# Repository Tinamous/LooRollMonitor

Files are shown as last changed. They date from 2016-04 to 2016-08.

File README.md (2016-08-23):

Toilet Roll Monitor
===================

Never run out of toilet paper again!

Internet collected toilet roll pole, constructed of a 3D printed base and a acrylic tube (pole) which the toilet paper rolls are stacked, internet connected with a Particle.io Photon.

The presense of toilet rolls are sensed with a IR reflectance sensor. Reflected IR signal == roll preset, no reflection == no roll.

Uses Photon with WiFi connection which is high power and 20mA drive for 3x IR LEDs, however the Photon can be put in low power mode (no WiFi)
and roll sensing only needs to be done occasionally.

## Why:
* Why not ;-)
* Guest bathrooms you don't check all that often - get notification on low toilet paper before your guess runs out.
* Day to day automation, never forget to order toilet paper again.

### Design issues:

#### V1: 
* Somewhat high power using photon and WiFi, most likely batteries will runout before toilet paper!
* Multiboard design clumsy to solder together but flexible from 1 to 4 roll sensors
* limited connections means all leds are driven at once (@20mA), so 3 roll system sees 60mA spike
* PCB mounted AA battery holders were just a bit too big to fit in the acrylic tube so batteries embedded in the 3D printed base.
* Humidity/temperature sensor, maybe not so useful? Difficult to solder on.

### V2 Options:
* Replace Photon with Bluz (or Zigbee + SmartThings combo).
* Single board to allow better signal routing and less soldering of connections.
* Possible to use PCB mounted coin cells if Bluz low power enough 
* Use through hole version of sensor for easier soldering

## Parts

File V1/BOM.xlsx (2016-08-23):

R1 | 100R | 1206
R2
R3 | 4k7 | 1206
R4 | 4k7 | 1206
R5 | 100k | 1206
R6 | 100k | 1206
R7 | 1k | 1206
C1 | 0.1uF | 805
U1 | HTU21D
D1 | LED | 1206 Reverse

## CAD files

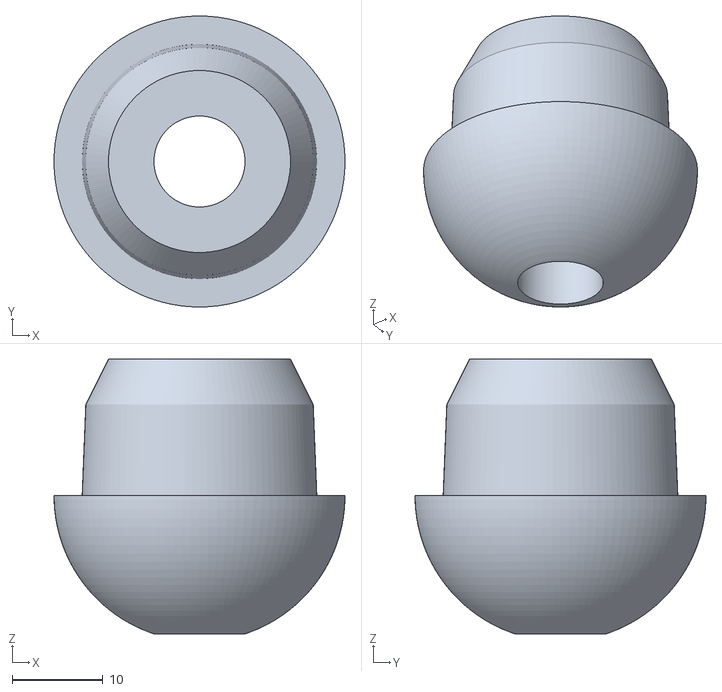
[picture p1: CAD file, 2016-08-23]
3DPrinted/Top.stl
32.0 x 32.0 x 30.2

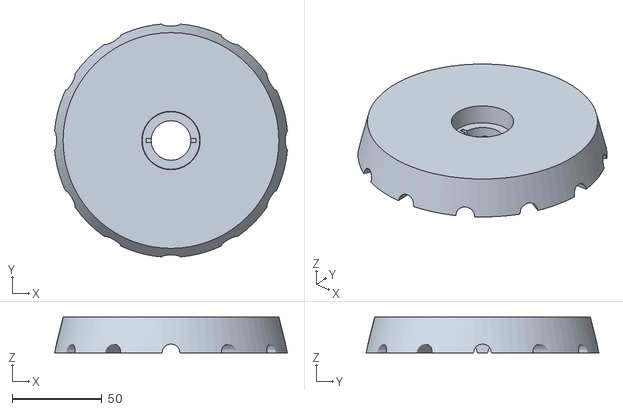
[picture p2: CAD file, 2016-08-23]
3DPrinted/Base-2.stl
129.6 x 129.6 x 20.0

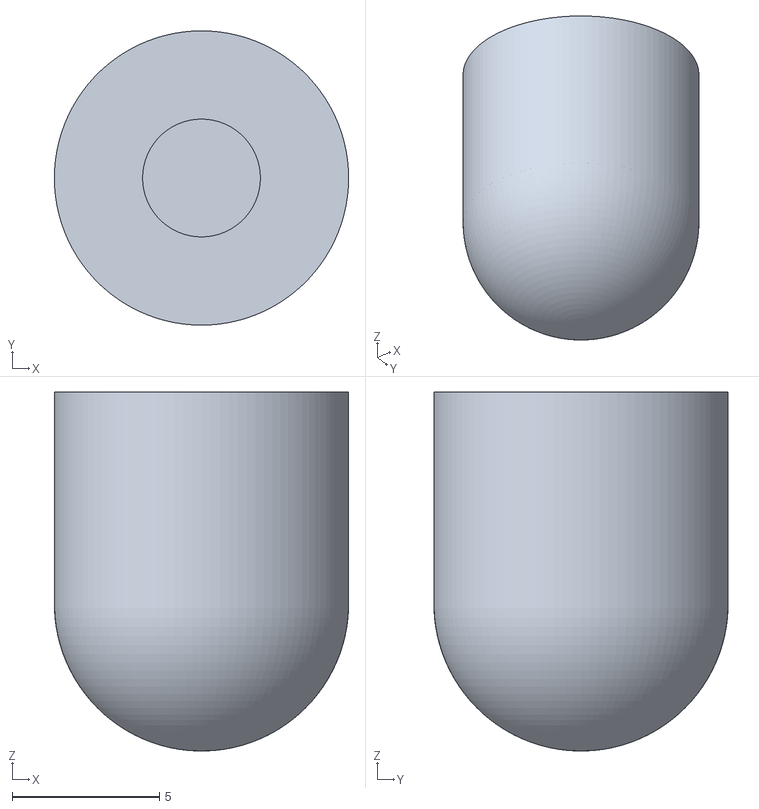
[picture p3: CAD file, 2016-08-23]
3DPrinted/RearPadding.stl
10.0 x 10.0 x 12.2

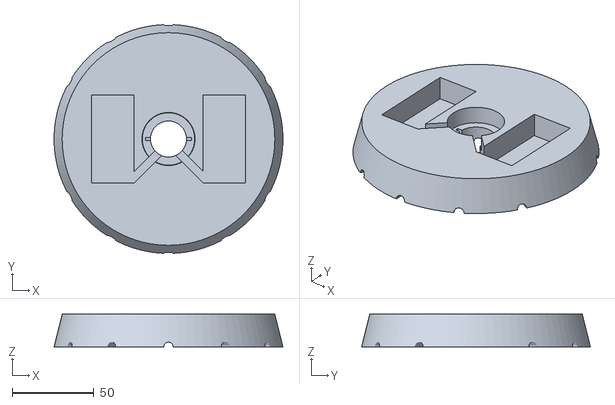
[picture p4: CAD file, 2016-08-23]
3DPrinted/Base-AAA.stl
140.0 x 139.8 x 20.0

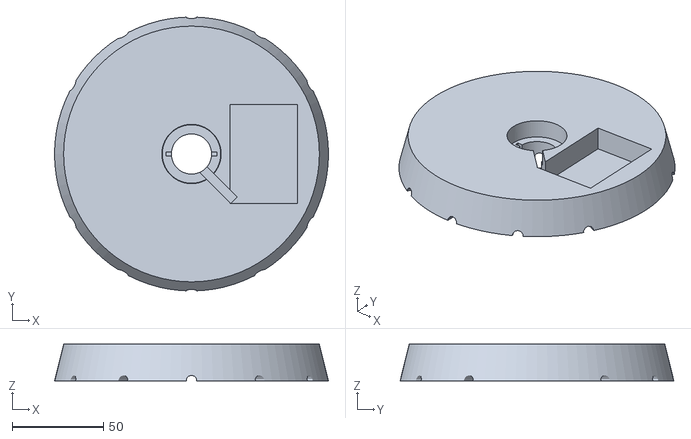
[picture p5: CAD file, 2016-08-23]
3DPrinted/Base.stl
150.0 x 149.8 x 20.0

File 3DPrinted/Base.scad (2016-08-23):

// The height of the base.
baseHeight = 20;
baseRadius = 65; 

// Size of the clear acrylic tube
tubeSize = 32; 
// How far down into the base the tube is expected to go
tubeDepthInBase = baseHeight - 10;

// LiPol cell
//batteryBoxWidth = 37; 
//batteryBoxLength = 54;
//batteryBoxDepth = 13;

// AAA battery.
batteryBoxWidth = 26;
batteryBoxLength = 54;
batteryBoxDepth = 14;



// series of releafes in the base to allow water to run through
// for the water detection part
module waterHoles() {
    for (angle = [30 : 30 : 150]) {
        rotate(a=[angle,90,0]) {
            cylinder(d=6, h=baseRadius+10);
        }
    }
    
    for (angle = [210 : 30 : 330]) {
        rotate(a=[angle,90,0]) {
            cylinder(d=6, h=baseRadius+10);
        }
    }  
}

module batteryCompartment(isTop) {
    translate([(tubeSize/2)+5,-(batteryBoxLength/2), (baseHeight-batteryBoxDepth)]) {
        cube([batteryBoxWidth,batteryBoxLength,batteryBoxDepth]);
        translate([-23,0,0]) {
            //cube([24,5,batteryBoxDepth]);
            translate([0,0,-1]) {
                //cube([5,16,batteryBoxDepth+1]);
            }
        }
        
        if (isTop) {
            translate([4,3.5,0]) {
                rotate(a=135) {
                    cube([28,5,batteryBoxDepth]);
                }
            }
        } else {
            
            translate([0,batteryBoxLength,0]) {
                rotate(a=225) {
                    cube([28,5,batteryBoxDepth]);
                }
            }
        }
    }
}

module base() {
    difference() {
        union() {
            cylinder(r1=baseRadius+5, r2=baseRadius, h=baseHeight, $fn=80);
        }
        union() {
            waterHoles();
            
            batteryCompartment(true);
            
            rotate(a=180) {
                batteryCompartment(false);
            }
            
            // Small inner hole all the way through
            // diameter to match the PCB narrow width used for the 
            // water sensor.
            cylinder(d=22, h=baseHeight, $fn=80);
            
            // 2 vertical pockets for the PCB to rest into.
            translate([10,-1,2]) {
                #cube([4,2,baseHeight]);
            }
            translate([-14,-1,2]) {
                #cube([4,2,baseHeight]);
            }
            
            // tube stops before the bottom of the base
            // Move up so the tube comes through the top of the base
            translate([0,0,baseHeight - tubeDepthInBase]) {
                // Slight angle to give it an easy in and snug fit.
                cylinder(d1=tubeSize, d2 = tubeSize+0.5, h=tubeDepthInBase, $fn=80);
            }
        }
    }
}


base();
//waterHoles();

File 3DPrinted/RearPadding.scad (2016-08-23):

// Tube ID 26mm
// PCB width = 1.6mm
// == 24.4mm to cover.
// /2 = 12.2mm padding either side of the PCB.
//
// 

$fn=100;
difference() {
    union() {
        // 14mm between PCB and tube.
        sphere(5); // 5mm rad. 
        cylinder(d=10,h=7.2); // 12.2 - 5 == 7.2
    }

    union() {
        translate([0,0,2]) {
            #cylinder(d=4,h=12.2);
        }
    }
}

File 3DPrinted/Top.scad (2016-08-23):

// Tube ID: 26mm
// Tube OD: 32mm 
// PCB width = 1.6mm


$fn=100;

module topBall() {
    difference() {
        union() {
            sphere(16);
            cylinder(d=10,h=7.2);
        }
        union() {
            translate([-16,-16,0]) {
                cube([32, 32, 32], centre=true);
            }
        }
    }
}


difference() {
    union() {
        topBall();
        // sloped cylinder to help fit
        cylinder(d1=25.8, d2=25, h=10);
        translate([0,0,10]) {
            cylinder(d1=25, d2=20, h=5);
        }
    }
    union() {
        translate([0,0,-20]) {
            #cylinder(d=10, h=40);
        }
    }
}

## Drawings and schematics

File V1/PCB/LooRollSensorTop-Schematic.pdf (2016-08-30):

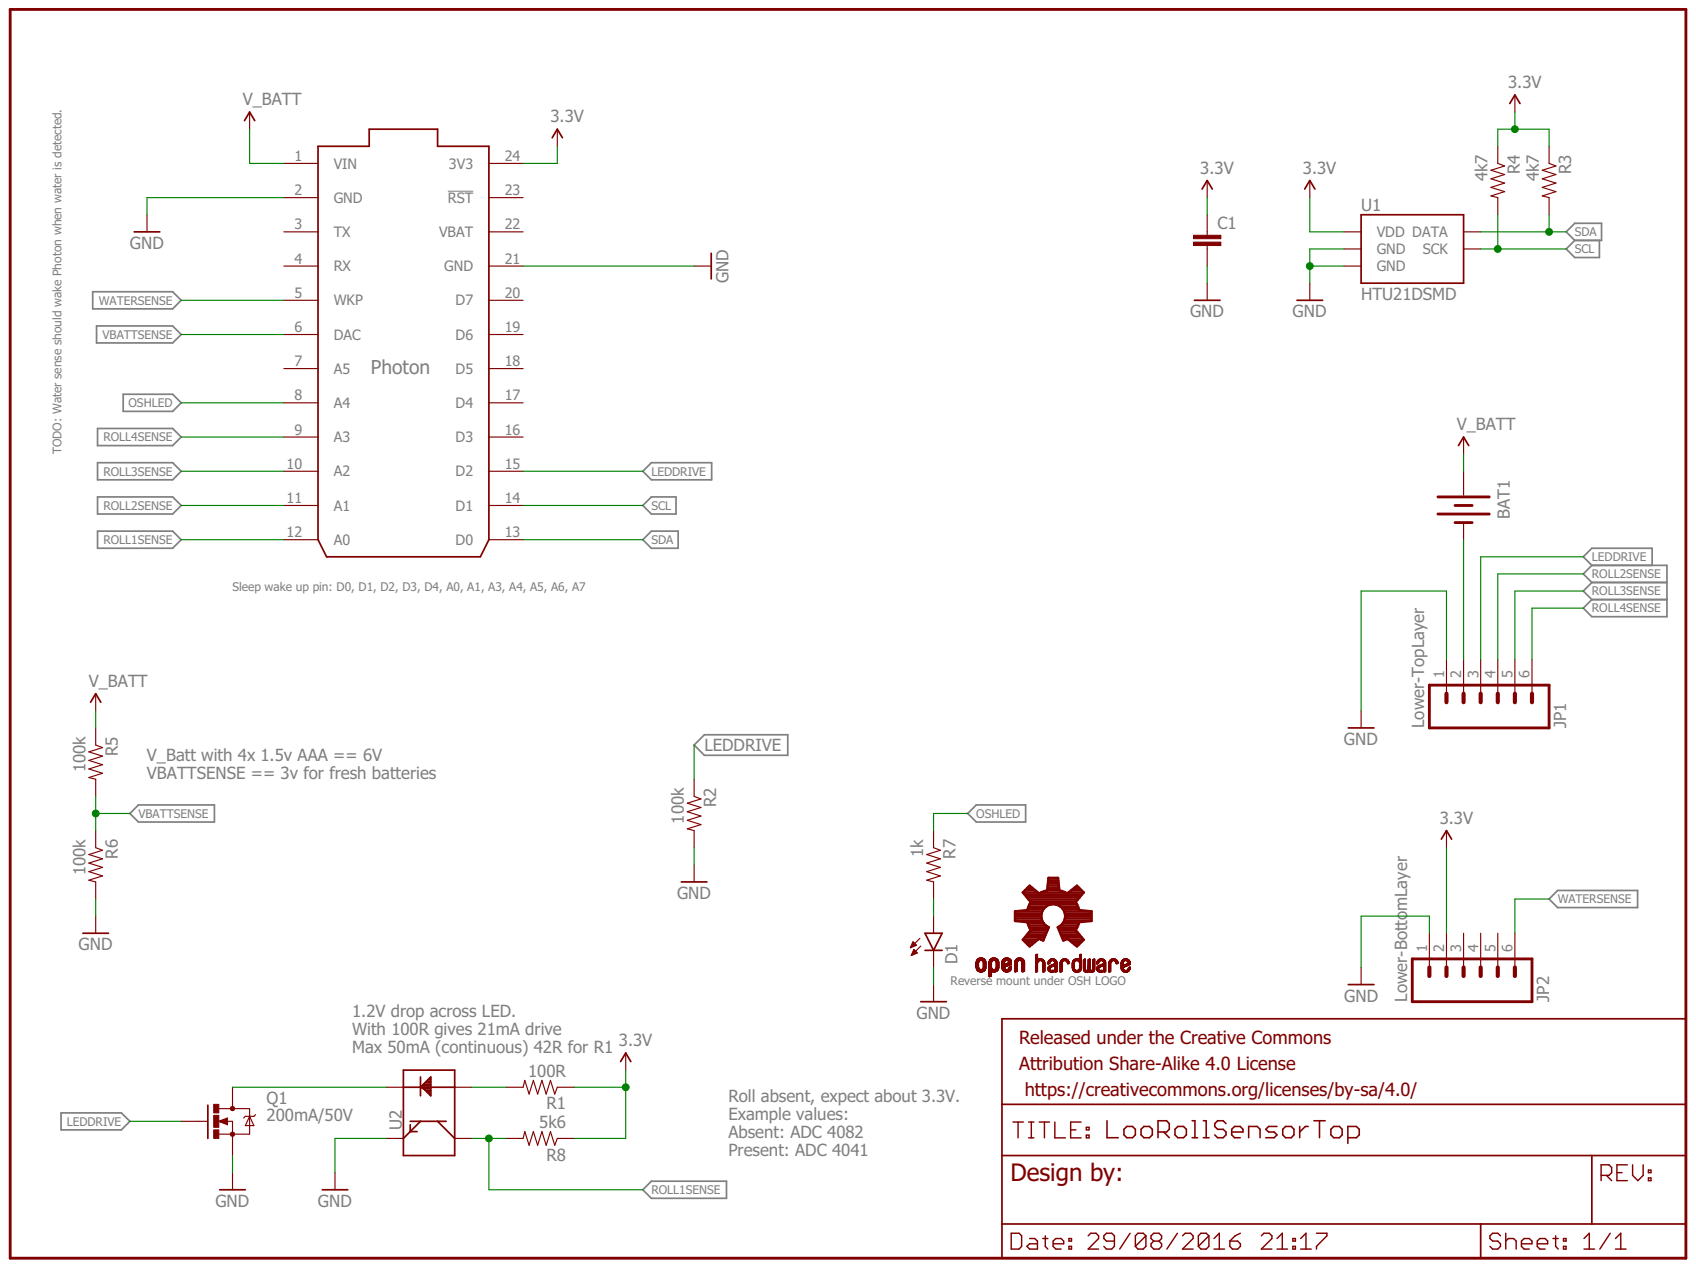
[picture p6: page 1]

TODO: Water sense should wake Photon when water is detected.

Sleep wake up pin: D0, D1, D2, D3, D4, A0, A1, A3, A4, A5, A6, A7

V_Batt with 4x 1.5v AAA == 6V
VBATTSENSE == 3v for fresh batteries

Reverse mount under OSH LOGO 1.2V drop across LED. With 100R gives 21mA drive Max 50mA (continuous) 42R for R1

Released under the Creative Commons Attribution Share-Alike 4.0 License https://creativecommons.org/licenses/by-sa/4.0/

Roll absent, expect about 3.3V. Example values: Absent: ADC 4082

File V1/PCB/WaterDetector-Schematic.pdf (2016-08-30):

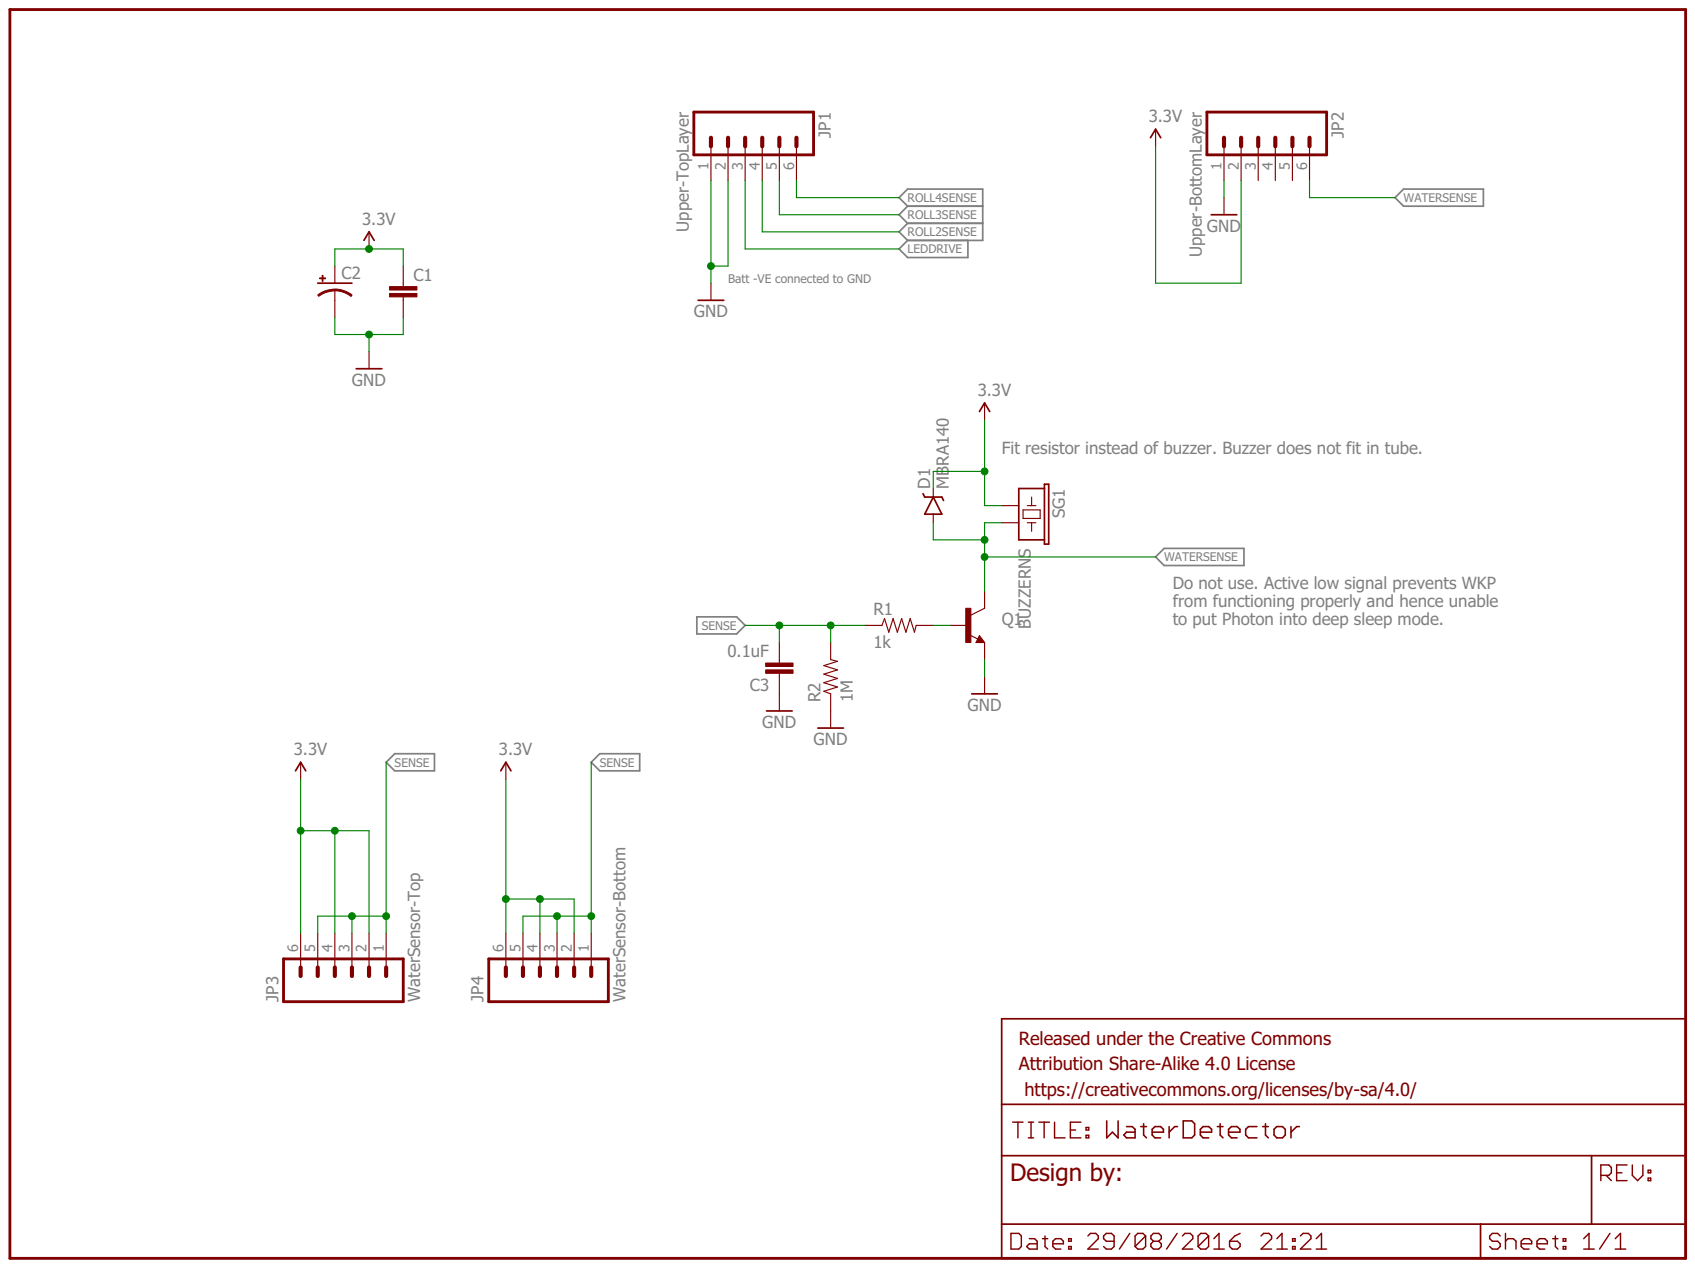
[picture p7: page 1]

Batt -VE connected to GND

Fit resistor instead of buzzer. Buzzer does not fit in tube.

Do not use. Active low signal prevents WKP
from functioning properly and hence unable
to put Photon into deep sleep mode.

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

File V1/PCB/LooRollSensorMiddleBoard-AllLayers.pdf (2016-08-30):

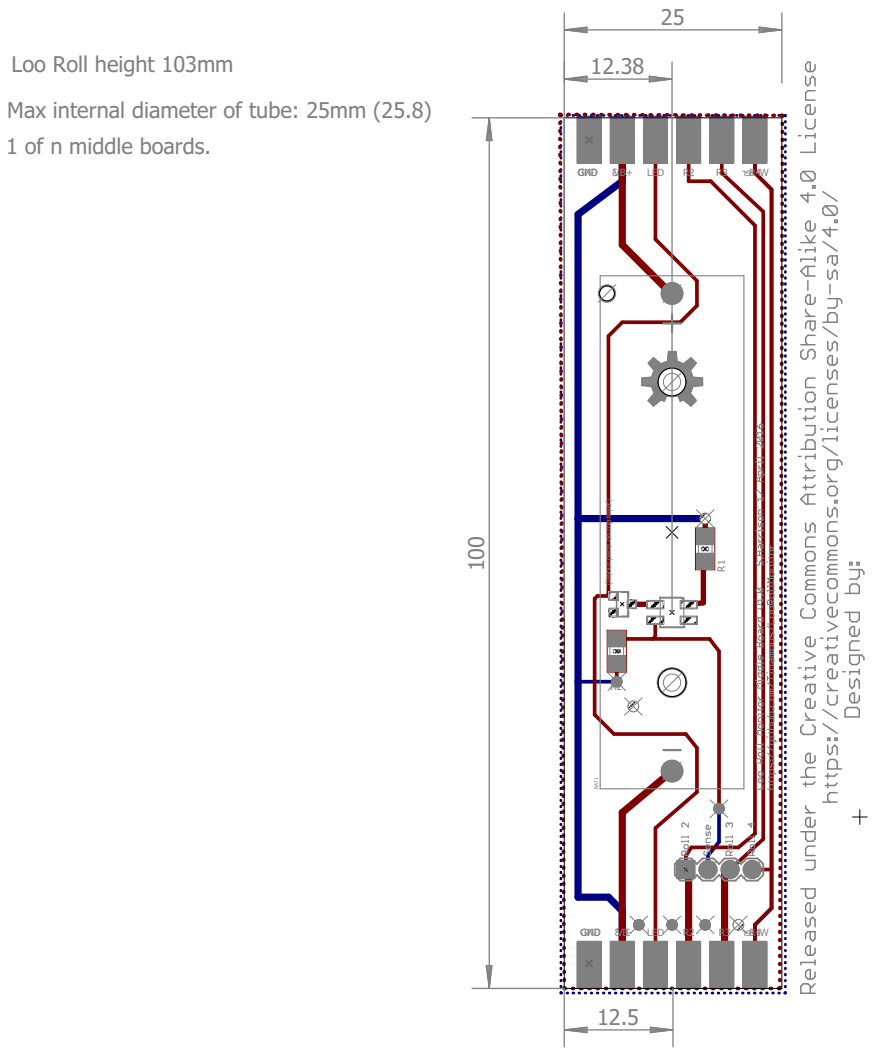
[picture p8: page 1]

Max internal diameter of tube: 25mm (25.8)

(layout parts on top layer)

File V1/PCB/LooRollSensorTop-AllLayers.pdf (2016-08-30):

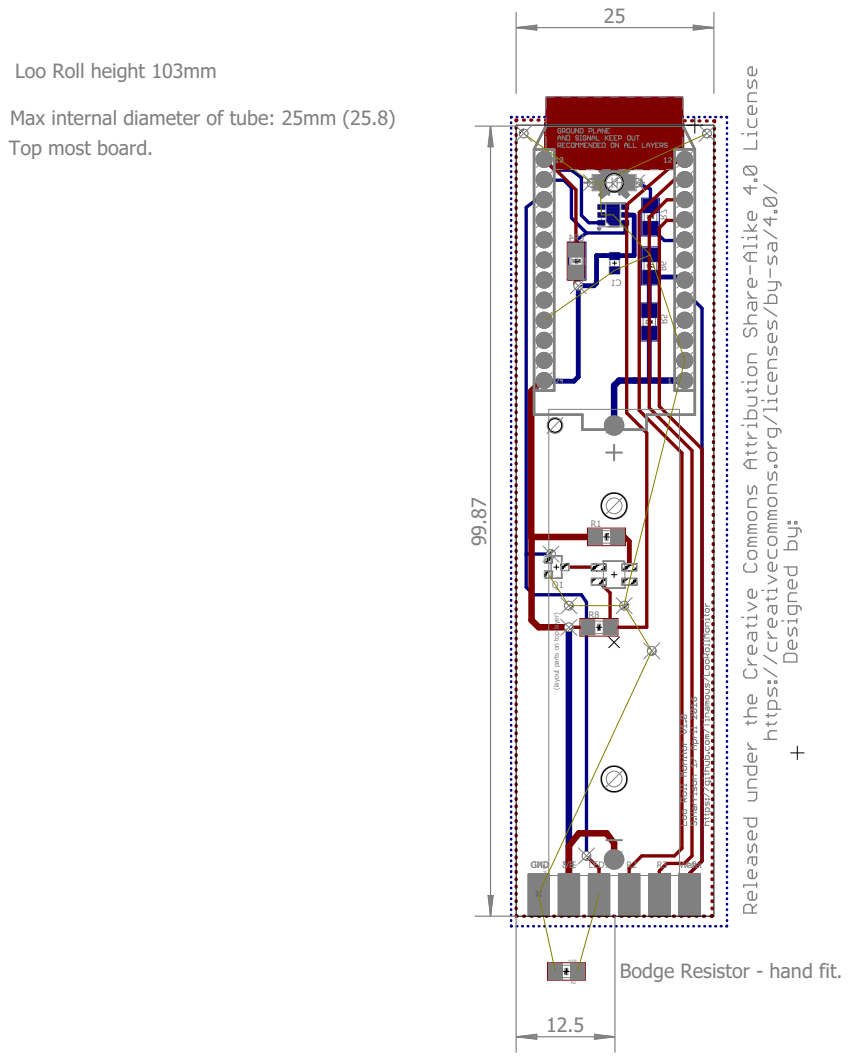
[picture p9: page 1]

Max internal diameter of tube: 25mm (25.8)

(layout parts on top layer)

Bodge Resistor - hand fit.

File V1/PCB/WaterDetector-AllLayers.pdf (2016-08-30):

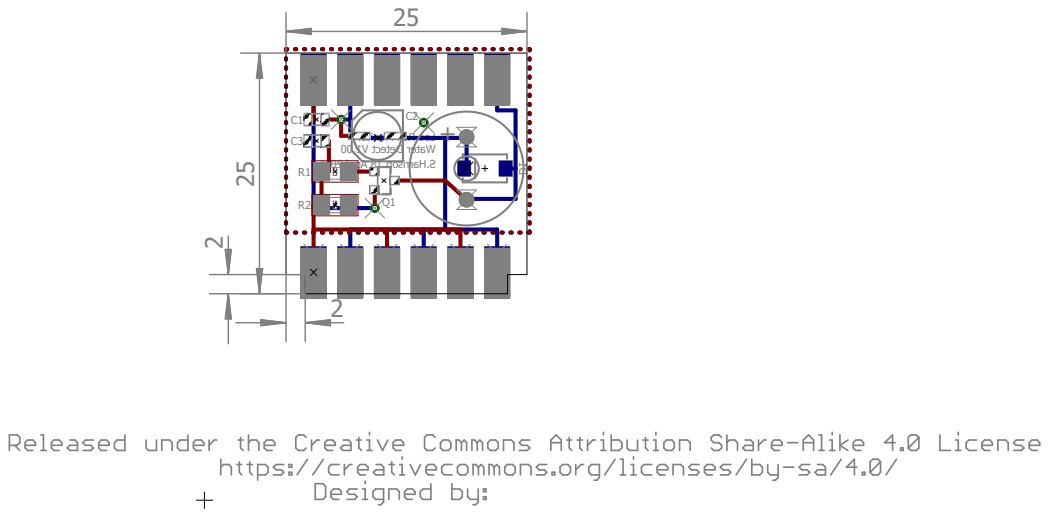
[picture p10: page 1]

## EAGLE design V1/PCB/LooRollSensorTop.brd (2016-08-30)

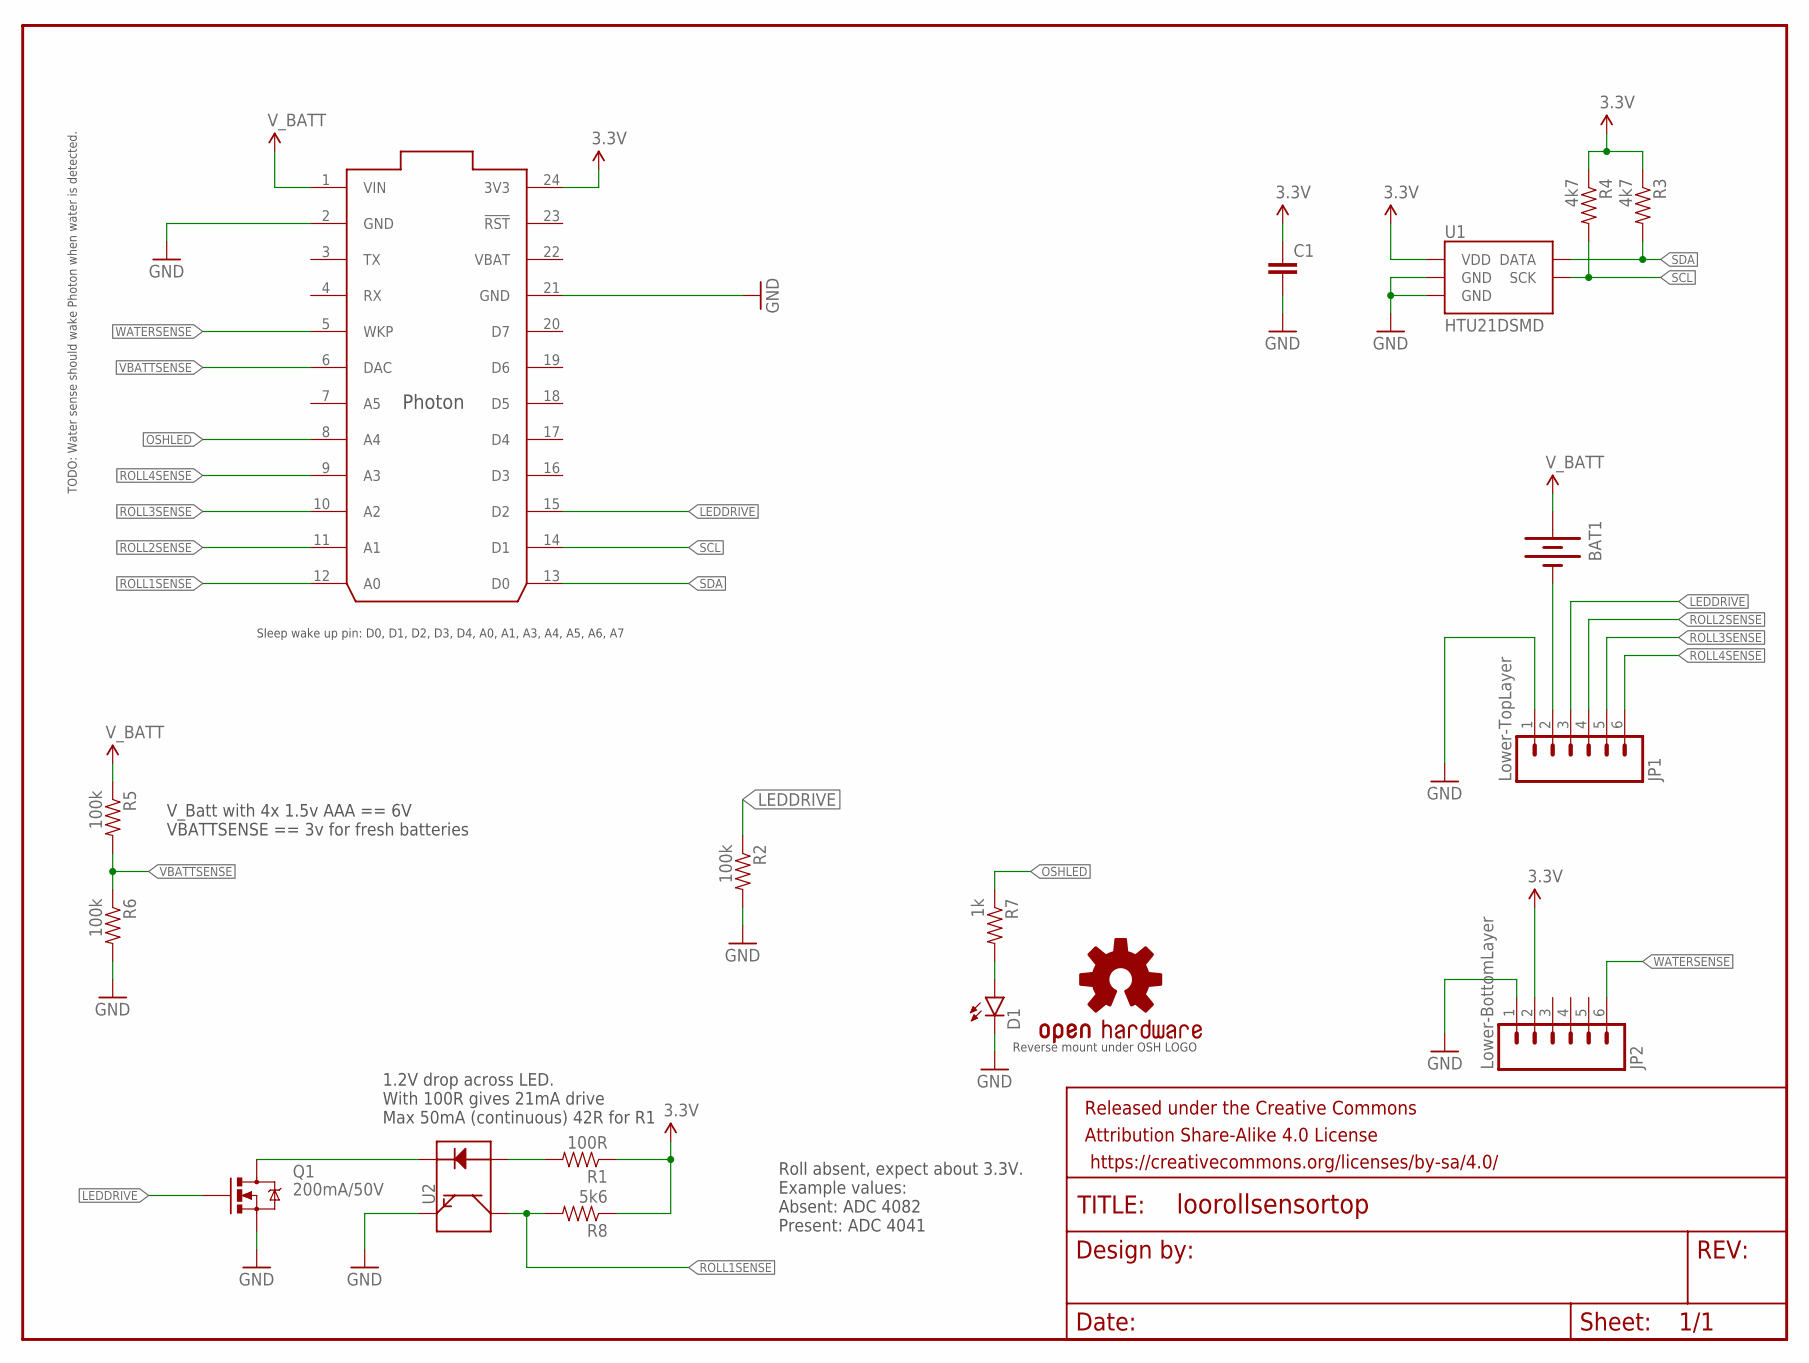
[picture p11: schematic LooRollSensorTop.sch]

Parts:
BAT1: BATTERYAA-PANEL; BATTERY-AA-PANEL; FARNELL 1650669
C1: CAP0805; 0805
D1: LED1206-BOTTOM; LED-1206-BOTTOM
FRAME1: FRAME-LETTER; CREATIVE_COMMONS
JP1: Lower-TopLayer; 1X06-SMD_EDGE
JP2: Lower-BottomLayer; 1X06-SMD_EDGE
LOGO1: OSHW-LOGOM; OSHW-LOGO-M
Q1: 200mA/50V; SOT23-3
R1: 100R; 1206
R2, R5, R6: 100k; 1206
R3, R4: 4k7; 1206
R7: 1k; 1206
R8: 5k6; 1206
U1: HTU21DSMD; HTU21D
U2: QRE1113SMD-W; QRE1113-W
U$1: PHOTON_WITH_HEADERS; PHOTON

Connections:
3.3V: C1.1, JP2.2, R1.1, R3.1, R4.1, R8.1, U1.VDD, U$1.24 (3V3)
GND: C1.2, D1.C, JP1.1, JP2.1, Q1.2 (S), R2.2, R6.2, U1.7 (GND), U1.GND, U2.4 (E), U$1.2 (GND), U$1.21 (GND)
LEDDRIVE: JP1.3, Q1.1 (G), R2.1, U$1.15 (D2)
unnamed: Q1.3 (D), U2.2 (K)
unnamed: R1.2, U2.1 (A)
unnamed: D1.A, R7.2
unnamed: BAT1.-, JP1.2
OSHLED: R7.1, U$1.8 (A4)
ROLL1SENSE: R8.2, U2.3 (C), U$1.12 (A0)
ROLL2SENSE: JP1.4, U$1.11 (A1)
ROLL3SENSE: JP1.5, U$1.10 (A2)
ROLL4SENSE: JP1.6, U$1.9 (A3)
SCL: R4.2, U1.SCK, U$1.14 (D1)
SDA: R3.2, U1.DATA, U$1.13 (D0)
VBAT: U$1.22 (VBAT)
VBATTSENSE: R5.2, R6.1, U$1.6 (DAC)
V_BATT: BAT1.+, R5.1, U$1.1 (VIN)
WATERSENSE: JP2.6, U$1.5 (WKP)

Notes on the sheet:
Sleep wake up pin: D0, D1, D2, D3, D4, A0, A1, A3, A4, A5, A6, A7
TODO: Water sense should wake Photon when water is detected.
Reverse mount under OSH LOGO
1.2V drop across LED. With 100R gives 21mA drive Max 50mA (continuous) 42R for R1
Roll absent, expect about 3.3V. Example values: Absent: ADC 4082 Present: ADC 4041
V_Batt with 4x 1.5v AAA == 6V VBATTSENSE == 3v for fresh batteries

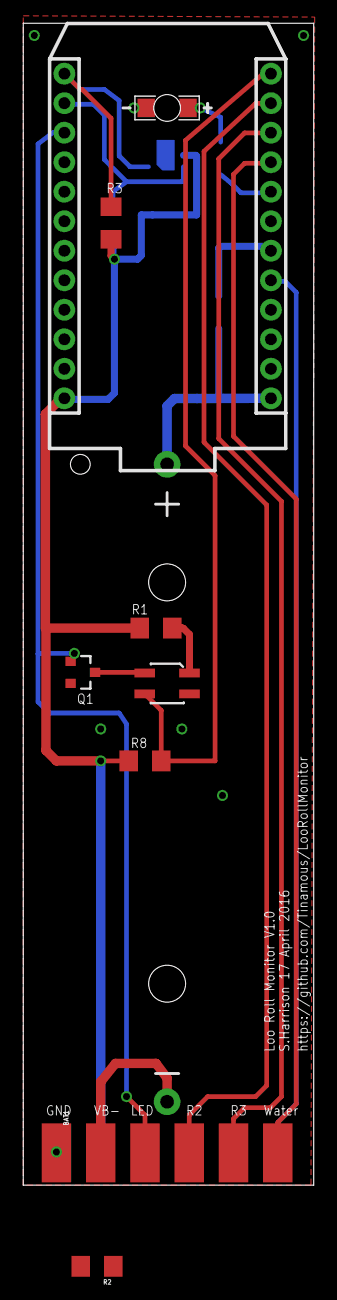
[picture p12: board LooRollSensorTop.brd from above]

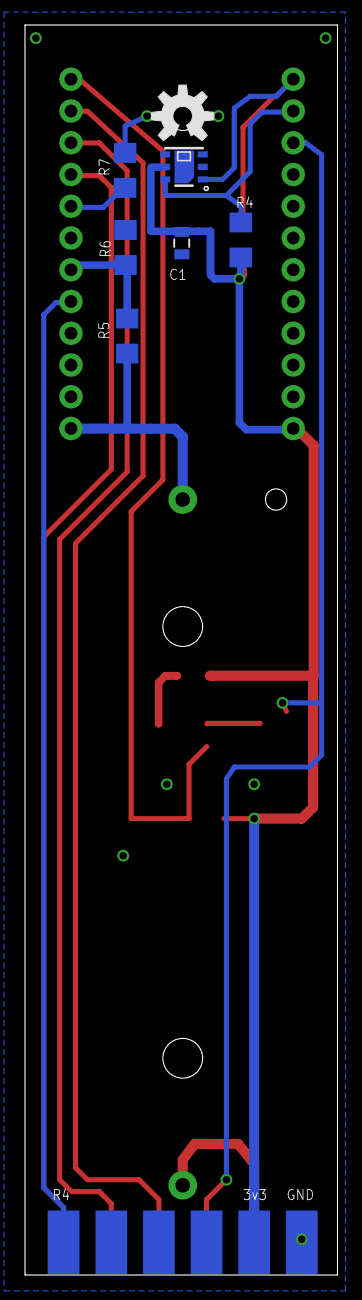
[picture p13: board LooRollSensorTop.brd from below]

Board: 2 copper layers, 25.0 x 100.0 mm, 19 parts (8 on the bottom side), 17 nets.

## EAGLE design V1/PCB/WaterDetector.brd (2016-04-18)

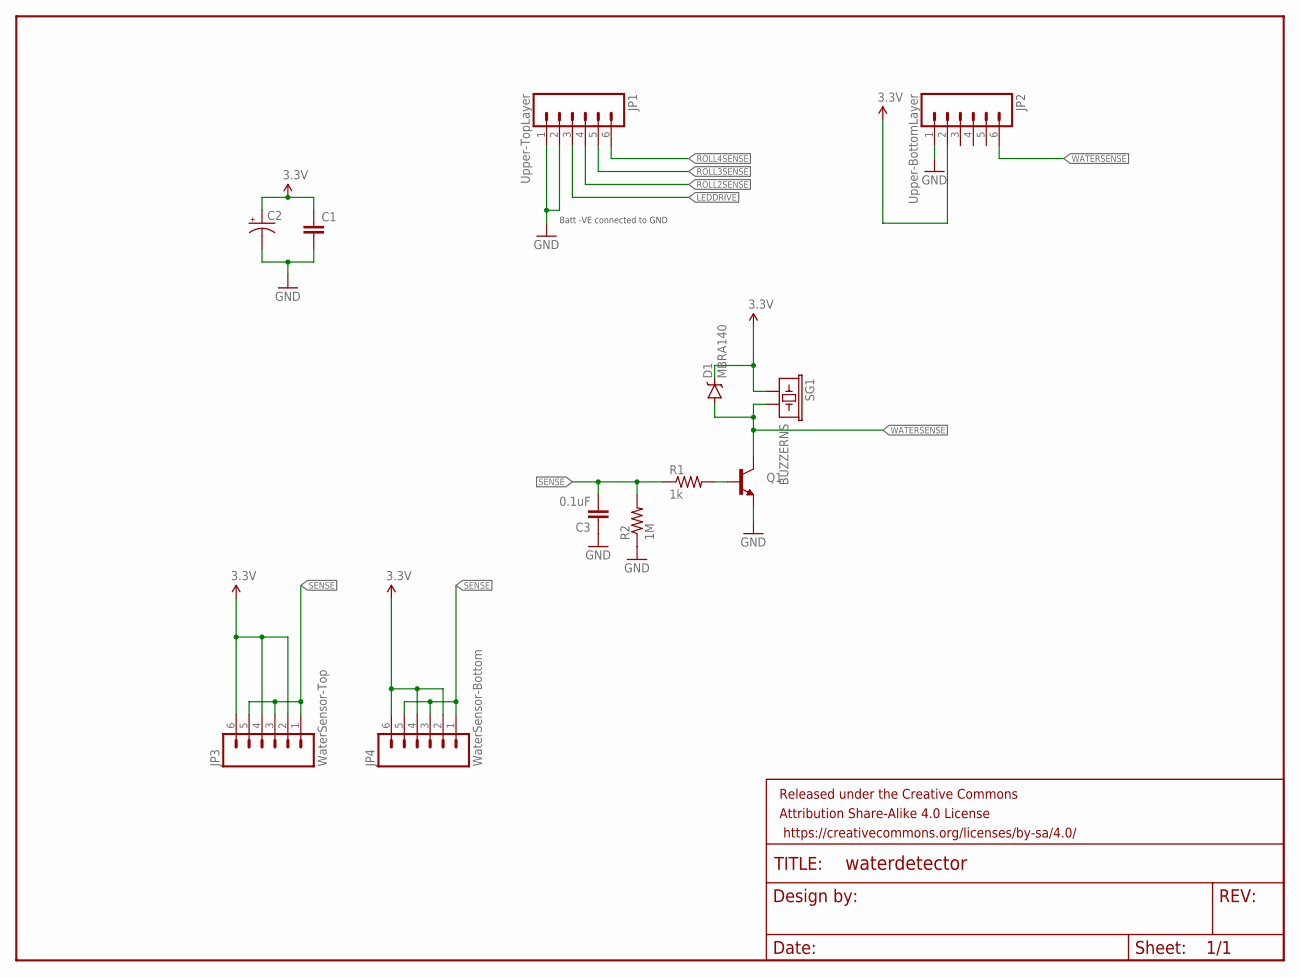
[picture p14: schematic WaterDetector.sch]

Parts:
C1: CAP0805; 0805
C2: CAP_POLC; PANASONIC_C
C3: 0.1uF; 0805
D1: MBRA140; SMA-DIODE
FRAME1: FRAME-LETTER; CREATIVE_COMMONS
JP1: Upper-TopLayer; 1X06-SMD_EDGE
JP2: Upper-BottomLayer; 1X06-SMD_EDGE
JP3: WaterSensor-Top; 1X06-SMD_EDGE
JP4: WaterSensor-Bottom; 1X06-SMD_EDGE
Q1: TRANSISTOR_NPNSOT23-3; SOT23-3
R1: 1k; 1206
R2: 1M; 1206
SG1: BUZZERNS; BUZZER-12MM-NS

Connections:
3.3V: C1.1, C2.+, D1.C, JP2.2, JP3.2, JP3.4, JP3.6, JP4.2, JP4.4, JP4.6, SG1.+ (1)
GND: C1.2, C2.-, C3.1, JP1.1, JP1.2, JP2.1, Q1.2 (E), R2.1
LEDDRIVE: JP1.3
unnamed: Q1.1 (B), R1.2
ROLL2SENSE: JP1.4
ROLL3SENSE: JP1.5
ROLL4SENSE: JP1.6
SENSE: C3.2, JP3.1, JP3.3, JP3.5, JP4.1, JP4.3, JP4.5, R1.1, R2.2
WATERSENSE: D1.A, JP2.6, Q1.3 (C), SG1.- (2)

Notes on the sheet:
Batt -VE connected to GND

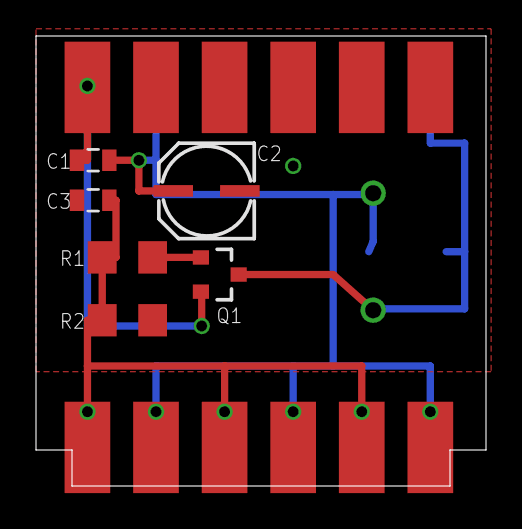
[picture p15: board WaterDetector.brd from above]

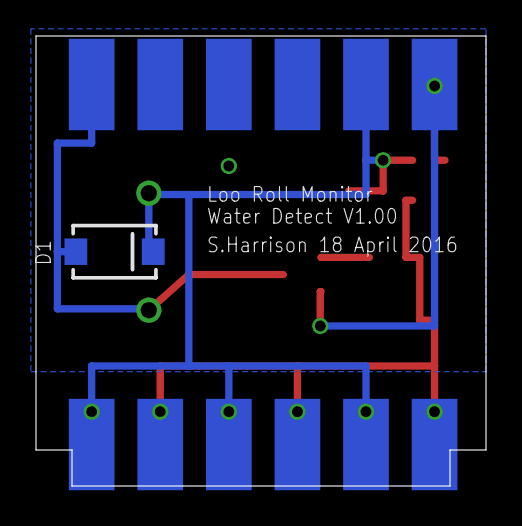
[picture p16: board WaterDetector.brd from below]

Board: 2 copper layers, 25.0 x 25.0 mm, 13 parts (3 on the bottom side), 5 nets.

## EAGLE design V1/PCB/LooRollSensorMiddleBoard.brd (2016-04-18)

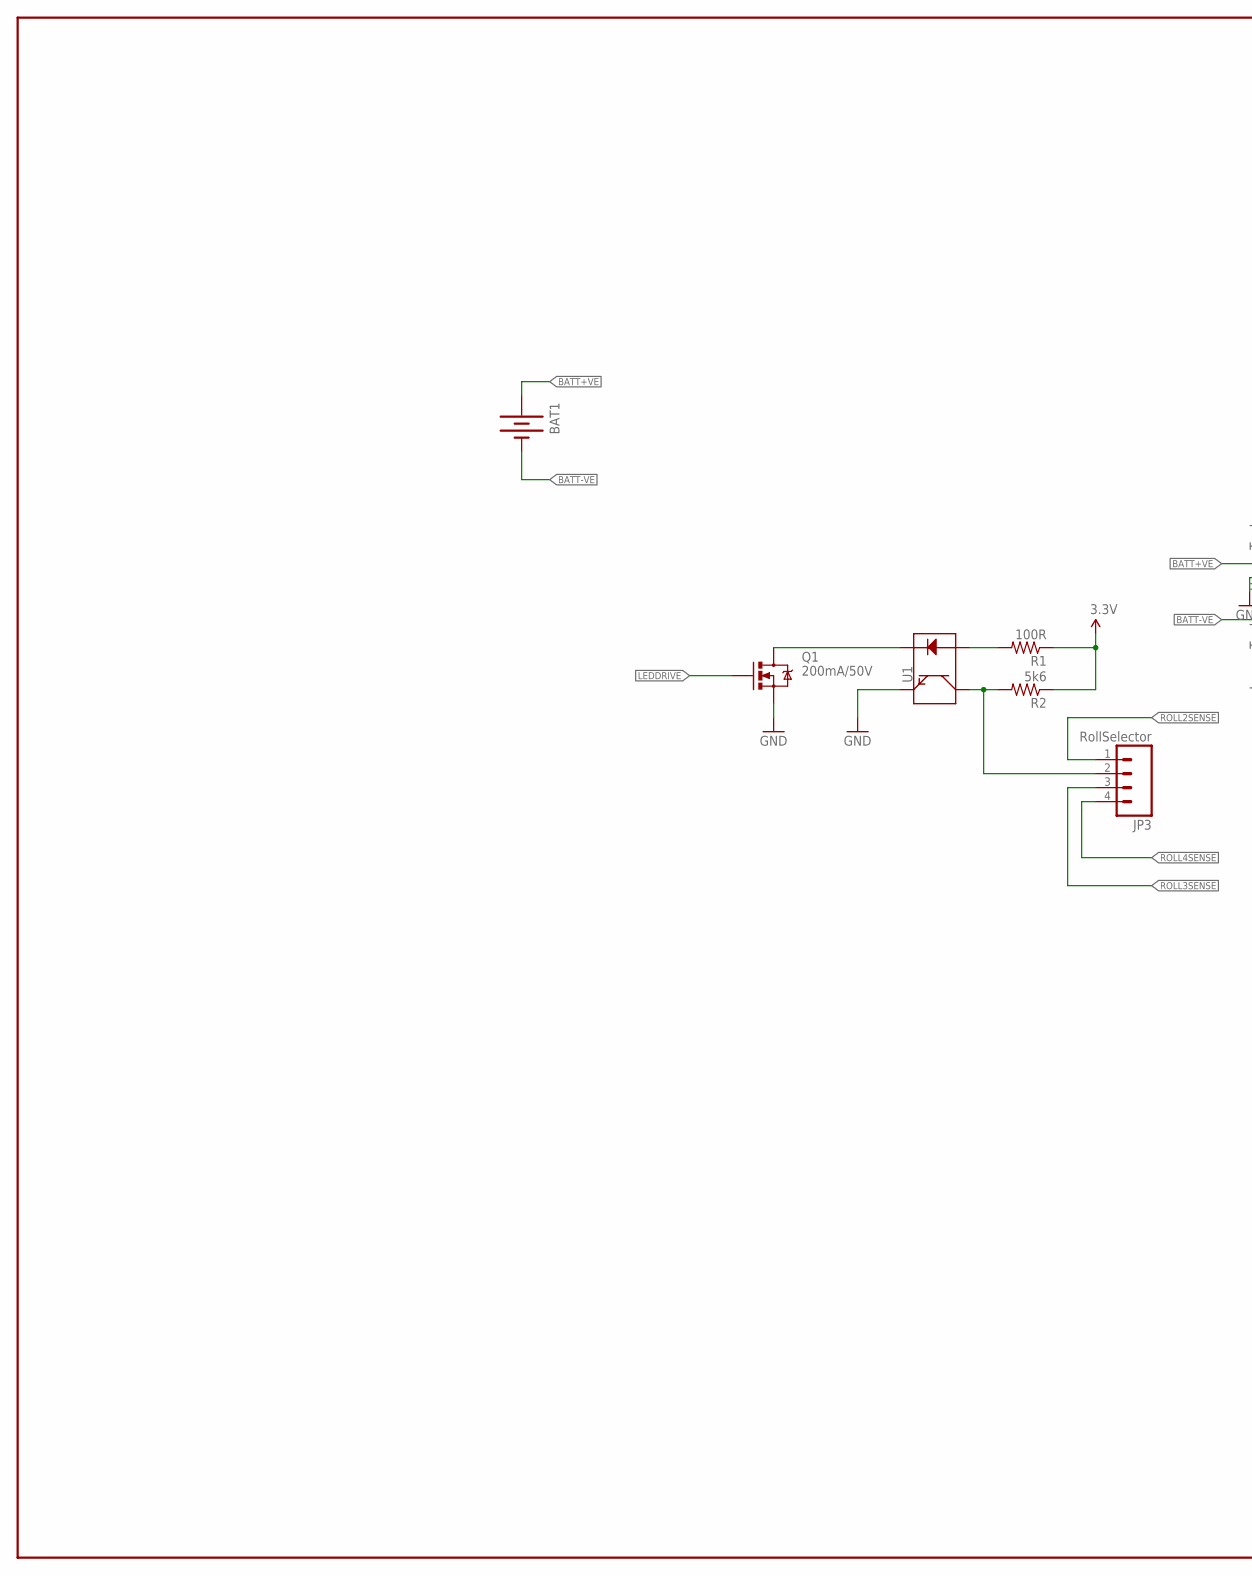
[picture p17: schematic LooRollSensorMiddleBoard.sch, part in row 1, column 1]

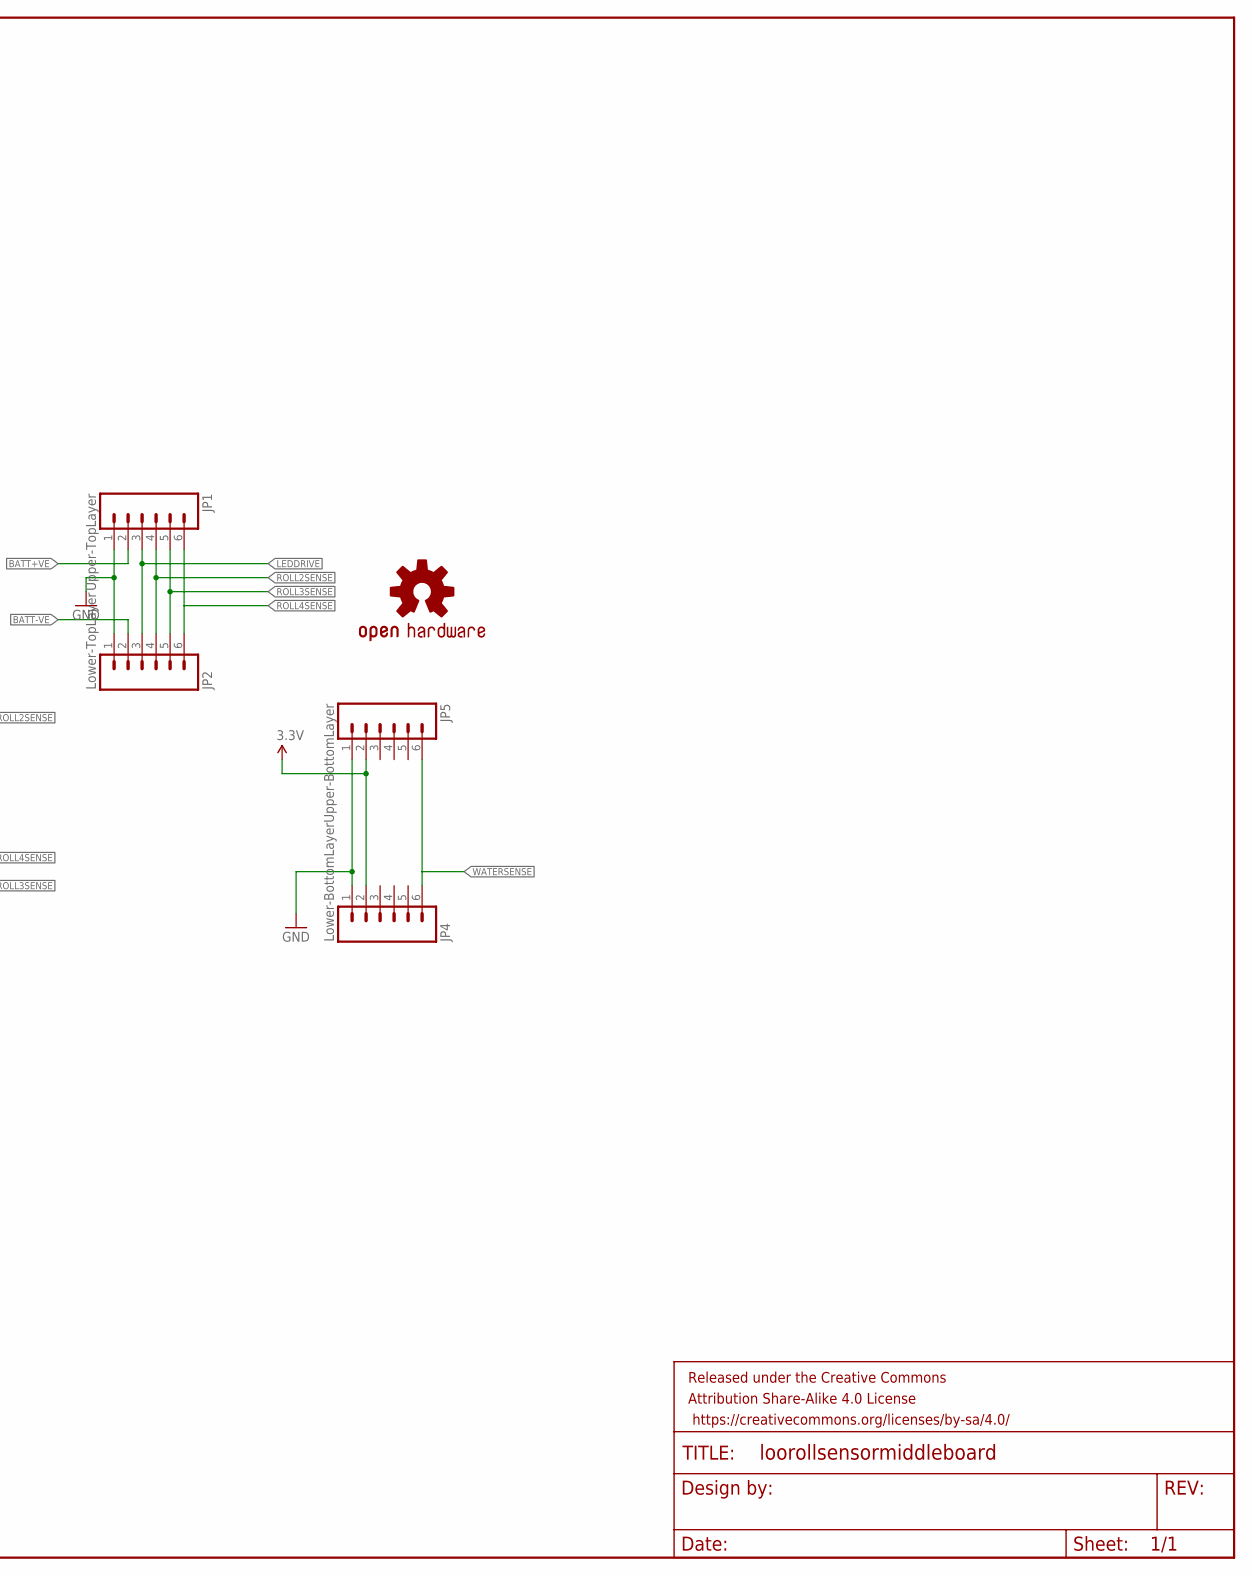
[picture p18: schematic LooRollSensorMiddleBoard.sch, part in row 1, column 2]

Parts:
BAT1: BATTERYAA-PANEL; BATTERY-AA-PANEL
FRAME1: FRAME-LEDGER; CREATIVE_COMMONS
JP1: Upper-TopLayer; 1X06-SMD_EDGE
JP2: Lower-TopLayer; 1X06-SMD_EDGE
JP3: RollSelector; 1X04
JP4: Lower-BottomLayer; 1X06-SMD_EDGE
JP5: Upper-BottomLayer; 1X06-SMD_EDGE
LOGO1: OSHW-LOGOL; OSHW-LOGO-L
Q1: 200mA/50V; SOT23-3
R1: 100R; 1206
R2: 5k6; 1206
U1: QRE1113SMD-W; QRE1113-W

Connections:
3.3V: JP4.2, JP5.2, R1.1, R2.1
BATT+VE: BAT1.+, JP1.2
BATT-VE: BAT1.-, JP2.2
GND: JP1.1, JP2.1, JP4.1, JP5.1, Q1.2 (S), U1.4 (E)
LEDDRIVE: JP1.3, JP2.3, Q1.1 (G)
unnamed: Q1.3 (D), U1.2 (K)
unnamed: R1.2, U1.1 (A)
ROLL2SENSE: JP1.4, JP2.4, JP3.1
ROLL3SENSE: JP1.5, JP2.5, JP3.3
ROLL4SENSE: JP1.6, JP2.6, JP3.4
ROLL_SENSE: JP3.2, R2.2, U1.3 (C)
WATERSENSE: JP4.6, JP5.6

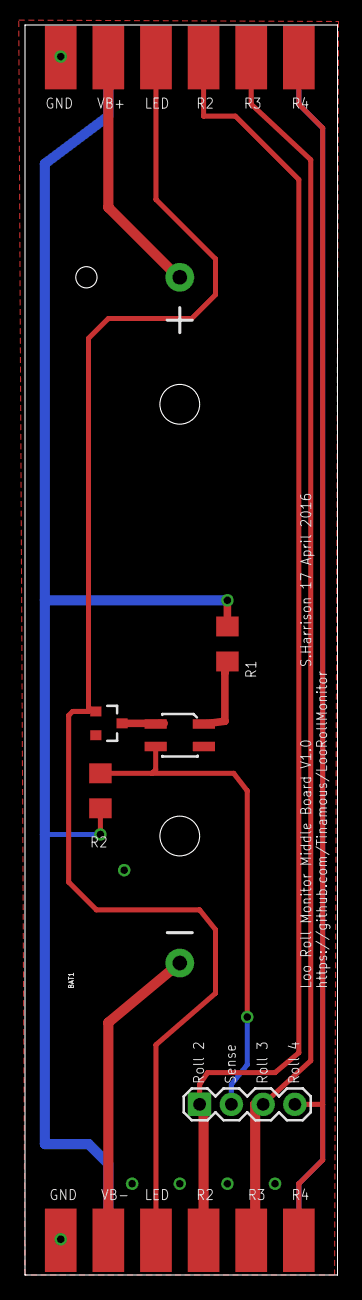
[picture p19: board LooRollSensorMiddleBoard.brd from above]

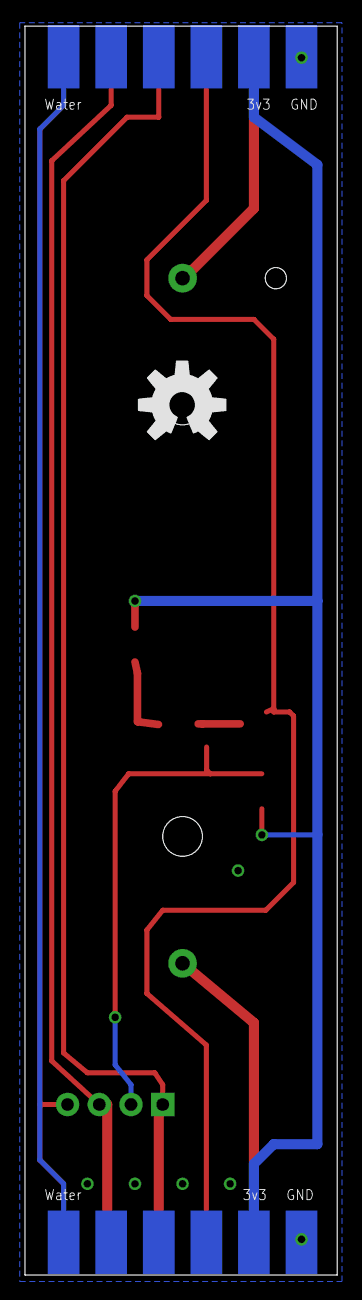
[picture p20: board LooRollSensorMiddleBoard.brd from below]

Board: 2 copper layers, 25.0 x 100.0 mm, 12 parts (3 on the bottom side), 12 nets.

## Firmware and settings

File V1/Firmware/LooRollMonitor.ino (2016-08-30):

// =========================================================================
// Toilet roll monitor - V1 PCB.
// Apache V2 License.
// Author: Stephen Harrison
// =========================================================================

// Each sensor has a small range of values between roll present and absent, 
// a value above the adcThresholds[] value for the sensor sets the roll as 
// not being present. A lower ADC value (more reflectance) indicates a roll present.
// 
// Each sensor is individually calibrated first (cal1) with no roll present to get a
// no reflection value, then with a roll present (cal2) to get the value with a roll present.
// The ADC threshold is set as the midpoint between the cal1 and cal2 value 
//
// **************************************************************************
// On first run, no rolls should be fitted and the baseline is taken.
// Rolls should then be fitted and a Cal2 triggered (call the particle function "calibrate" with the argument value "2")
// Cal 1 can be repeated by calling the "calibrate" function with argument value "1" first if this is desired.
// both Cal1 and Cal2 need to be run to determine the correct threshold for each sensor.
// Cal2 MUST be run after a Cal1.
// **************************************************************************
//
// ADC values and roll count are stored in EEPROM.
// When the roll count changes a senml message is published with the roll count.
// 

STARTUP(System.enableFeature(FEATURE_RETAINED_MEMORY));

// How long to sleep for when entering deep sleep.
// Development: 30s...
//int deepSleepTimeSeconds = 60;
// Production: 3600 (1 hour) or more is usable
int deepSleepTimeSeconds = 3600;

int debugSleepSeconds = 10;

// The maximum number of sensors on the board. values 1-4 acceptable.
uint8_t maxSensors = 3;

// Default initial debugging setting to publish ADC values as they are read.
bool publishAdcValues = false;

// Initialise to defaults but calibrated values are loaded 
// from EEPROM if the value is stored.

// Empty/full threshold value. 
uint16_t adcThresholds[] =  {3990, 3990, 3990, 3990};

// Cal 1 ADC values for no roll present
uint16_t adcEmpty[] =  {4096, 4096, 4096, 4096}; 

// CAL 2 ADC values with roll present.
uint16_t adcFull[] =  {3967, 3967, 3967, 3967}; 

// 0: Not claibrated. 
// 1: Cal 1 (no roll)
// 2: Cal 2 (roll present)
uint8_t calibrationState = 0; 

// The minimum number of rolls. When the roll count hits this value
// the low roll warning is triggered.
uint8_t minimumRollCount = 1;

// The number of loo rolls detected.
// Stored in backupd ram so will be kept between
// deep sleeps
retained uint8_t looRollCount = -1;

// Individual sensor values for the rolls.
bool hasRoll[] = {false, false, false, false};

// The ADC values read for the rolls.
int adcValues[] = {0,0,0,0};

// Mapping for roll index to ADC/DIO pins.
int sensors[] = {A0, A1, A2, A3};
// V1 PCB, all sensors are using D2 for LED drive.
int leds[] = {D2, D2, D2, D2};
// V1 hardware has single drive pin
int ledPin = D2;

// "debug" led behind the OSH Logo.
int oshLogoLedPin = A4;

// Water sense pin.
int waterSensePin = WKP; // A7 - used also for water sense trigger.
// If water has been sensed.
int waterSensed = false;

// if water was sensed in the interrupt.
volatile int waterSenseTriggered = false;

// If the water sensed alert has been published
// Stored in backupd ram so will be kept between
// deep sleeps
retained int waterSensedPublished = false;

// Battery
// Battery voltage sense pin.
int vBattSensePin = DAC; // A6
int vBattAdc = 0;
int vBattThreshold = 3.8; // 3.8V cutoff for low battery
bool lowBattery = false;
double batteryVoltage = 0;

bool calibrating = false;
bool messagePublishedWithNoDelay = false;

retained bool isWakeFromPowerSave = false;

// how long between reset and set-up completing (i.e. connect)
unsigned long timeToConnect = 0;

// how long from reset to sleep (i.e. running on full power)
retained unsigned long timeToSleep = 0;

//////////////////////////////////////////////////////////////////////////
// Particle methods
//////////////////////////////////////////////////////////////////////////
int setMinRolls(String args);
int getCount(String args);
int calibrate(String args);
int getCalibration(String args);

//////////////////////////////////////////////////////////////////////////
// Setup
//////////////////////////////////////////////////////////////////////////
void setup() {
    RGB.control(true);
    RGB.brightness(25);
    // Blue to indicate set-up and not cleash with red/green of status
    RGB.color(0, 0, 255);
    
    for (int i=0; i<maxSensors; i++) {
        pinMode(sensors[i], INPUT);
        pinMode(leds[i], OUTPUT);
        digitalWrite(leds[i], LOW);
    }
    
    // OSH Logo (High power mode) LED
    pinMode(oshLogoLedPin, OUTPUT);
    digitalWrite(oshLogoLedPin, HIGH);
    
    // Water sense pin
    // This is used as the wake up pin
    // Active low digital input.
    // pinMode(waterSensePin, INPUT_PULLUP);
    
    // Battery sense. Analog input.
    pinMode(vBattSensePin, INPUT);
    
    // Debug
    pinMode(D7, OUTPUT);
    
    // Particle functions
    Particle.function("setMinRolls", setMinRolls);
    Particle.function("getCount", getCount);
    Particle.function("calibrate", calibrate);
    Particle.function("getCal", getCalibration);
    
    // Publish version info on first start only
    if (!isWakeFromPowerSave) {
        publishStatus("Loo Roll Monitor V0.5.15", false);
        
    }
    
    // Load in the ADC thresholds for the sensors and bits.
    readSettings();
    
    // Now attach the water sense interrupt.
    // only interested in falling edge to indicate water present
    // allow natural polling to clear it
    //attachInterrupt(waterSensePin, waterSenseIsr, FALLING);
    
    timeToConnect = millis();
}

void loop() {
    // Whilst in High power mode keep the OSH LED on to indicate high power.
    // recovering from sleep mode indication...
    digitalWrite(oshLogoLedPin, HIGH);
    RGB.brightness(25);
    
    if (!calibrating) {
        checkVBatt();
        checkWaterSense();
        
        // If the battery is low then hold off checking the rolls
        // as it may kill the battery.
        if (!lowBattery) {
            checkLooRoll();
        }
        
        // Show a warning (red) led if their is a problem.    
        // Do this before publishing so it's shown for a little bit longer.
        if (shouldShowWarning()) {
            RGB.color(255, 0, 0);
        } else {
            RGB.color(0, 255, 0);
        }
        
        if (!lowBattery) {
            publishSystemState();
        }
    }
    
    sleep();
}

// Determine if a warning LED should be shown
// e.g. Battery low, water sensed or loo roll count is low.
bool shouldShowWarning() {
    if (looRollCount <= minimumRollCount) {
        return true;
    }
        
    if (waterSensedPublished) {
        return true;
    }
            
    if (lowBattery) {
        return true;            
    }
    
    return false;
}

// Sleep the Photon, depending on how long it's been awake
// either heavy sleep, or light sleep to help debugging.
void sleep() {
    // millis not affected by sleep.
    unsigned long t = millis();
    
    // If more than n minutes since the power on
    // then go into Low power mode, or if the power-up
    // was caused by a deep sleep power down.
    if (isWakeFromPowerSave || t > (120 * 1000)) {
        
        // Small delay to ensure any messages that needed to be 
        // pushed to Particle are gone before sleeping.
        if (messagePublishedWithNoDelay) {
            delay(2000);
        }
        
        digitalWrite(oshLogoLedPin, LOW);
        
        // Next power-up will not be the initial one
        // so the delay before sleeping can be ignored.
        //isInitialPowerUp = false;
        isWakeFromPowerSave = true;
        timeToSleep = millis();
        
        // Deep sleep: wake after n seconds or rising edge on WKP
        // (water sense pin) - however water sense is active low so wkp 
        // will only trigger 
        // NB: Need pull-down for LED drive to ensure LEDs are not
        // turned on when in deep sleep.
        // WKP being high because of water sense appears to break
        // this being pulled out of deep sleep.
        System.sleep(SLEEP_MODE_DEEP, deepSleepTimeSeconds);
        
        // Stop mode: wake after n seconds or falling edge on water sense pin.
        // This sleep mode keeps memory preserved and allows for falling signal
        // on interrupt pin (WKP here) to wake up.
        // however it uses ca. 1-2mA
        //System.sleep(waterSensePin, FALLING, deepSleepTimeSeconds);
        
        // Don't publish debug ADC values whilst in low power mode.
        publishAdcValues = false;
        
    } else {
        // Debug mode:
        // Check every 10 seconds and don't go into low power
        // Handy for debug or initial power up + firmware updates
        for (int i=0; i<debugSleepSeconds; i++) {
            delay(1000);
            // If water sensed then exit out of the delay
            // and allow the loop to process the status.
            if (waterSenseTriggered) {
                return;
            }
        }
        
        // Set true to help debugging.
        publishAdcValues = false;
    }
}

// Publish the system status (roll count, water sensed, battery level etc.)
void publishSystemState() {
    
    String senmlFields = "{'n':'rollCount','v':'" + String(looRollCount) + "'}";
    senmlFields += ",{'n':'WaterSensed','v':'" + String(waterSensed) + "'}";
    senmlFields += ",{'n':'VBatt','v':'" + String(batteryVoltage) + "'}";
    // Debug fields
    senmlFields += ",{'n':'A0','v':'" + String(adcValues[0]) + "'}";
    senmlFields += ",{'n':'A1','v':'" + String(adcValues[1]) + "'}";
    senmlFields += ",{'n':'A2','v':'" + String(adcValues[2]) + "'}";
    senmlFields += ",{'n':'TConn','v':'" + String(timeToConnect) + "'}";
    senmlFields += ",{'n':'TTS','v':'" + String(timeToSleep) + "'}";
    
    // Don't forget Temperature and humidity if they are measured.
    
    // Publish the number of rolls, water sense, 
    // publish this every wake cycle regardless to keep
    // monitor informed. 
    publishSenML("{e:[" + senmlFields +  "]}");
}

//////////////////////////////////////////////////////////////////////////////
// Roll detection
//////////////////////////////////////////////////////////////////////////////
void checkLooRoll() {
    
    int count = 0;
    
    // Work up the sensors from the lowest (A0)
    // to the highest (A3 or ...)
    // This is not the most optimal use of power but is easy...
    // It is also ignores gravity defying errors (e.g. base roll
    // may appear to be absent but rolls above present)
    for (int i=0; i<maxSensors; i++) {
        hasRoll[i] = hasLooRoll(i);
        if (hasRoll[i]) {
            count++;
        } 
    }
    
    // Check to see if the number of rolls has changed since we 
    // last measured and 
    if (count != looRollCount || publishAdcValues) {
        looRollCount = count;
        
        notifyLooRollCountChanged();
        
        // Store in EEPROM the count
        writeLooRollCount();
    }
}

void notifyLooRollCountChanged() {
    
    if (looRollCount <= minimumRollCount) {
        // Ensure we have a good delay for sending the message.
        publishStatus("Loo roll Low!!! Rolls remaining: " + String(looRollCount), true);
    }
        
    publishStatus("Rolls remaining: " + String(looRollCount), false);
}

// Read the IR sensor ADC value.
int readSensor(int sensorId) {
    int ledChannel = leds[sensorId];
    
    // Compute how much the ADC input is decreased due to background IR
    int adcBefore = analogRead(sensors[sensorId]);
    int background = 4096 - adcBefore; 
    
    // Enable the IR LED and measure the reflectance level
    // A lower ADC value means more reflectance.
    digitalWrite(ledChannel, HIGH);
    delay(400);
    int adc = analogRead(sensors[sensorId]);
    digitalWrite(ledChannel, LOW);
    delay(500);
    
    if (background > 10) {
        // Debug to catch possible background noise. Should not be 
        // sent under normal operation.
        publishStatus("background: " + String(background), false);
    }
    

    // Add the background value to the adc measured value to  compensate
    return adc + background;
}

// Determine if a loo roll is present at the sensor position.
// 0 is top, 3 is bottom (if fitted)
bool hasLooRoll(int sensorId) {

    adcValues[sensorId] = readSensor(sensorId);
    
    // If ADC reading below the threshold then
    // their is a roll there reflecting.
    return adcValues[sensorId] < adcThresholds[sensorId];
}

//////////////////////////////////////////////////////////////////////////////
// Water leak detection
//////////////////////////////////////////////////////////////////////////////
void checkWaterSense() {
    // Pin reads low if water is present.
    waterSensed = !digitalRead(waterSensePin);
    
    // trigger once only.
    if (waterSensed && !waterSensedPublished) {
        publishStatus("WATER LEAK DETECTED!", true);
        publishSenML("{e:[{'n':'WaterSensed','v':'" + String(waterSensed) + "'} ]}");
        waterSensedPublished = true;
        
        // Small delay to allow critical message to be published.
        delay(2000);
    }
    
    // If we have published water sense detected but it is not now.
    // then clear the warning
    if (!waterSensed && waterSensedPublished) {
        publishStatus("Water leak cleared.", false);
        publishSenML("{e:[{'n':'WaterSensed','v':'" + String(waterSensed) + "'} ]}");
        waterSensedPublished = false;
    }
    
    // Don't do any action on waterSenseTriggered
    // but use it to bring the photon out of low power mode.
    // clear it hear if it had been set by the interrupt
    waterSenseTriggered = false;
}

//////////////////////////////////////////////////////////////////////////////
// Battery monitor
//////////////////////////////////////////////////////////////////////////////
void checkVBatt() {
    vBattAdc = analogRead(vBattSensePin);
    
    // VBatt is split by voltage divider 2:1
    batteryVoltage = ((double)vBattAdc * 0.0008) * (double)2; 
    
    // trigger once only.
    if (!lowBattery && batteryVoltage < vBattThreshold) {
        lowBattery = true;
        publishStatus("Battery Low!", true);
    } 
}

//////////////////////////////////////////////////////////////////////////////
// Particle methods
//////////////////////////////////////////////////////////////////////////////

// Set the minimum number of rolls acceptable
int setMinRolls(String args) {
    int minimumRollCount = args.toInt();
    writeSettings();
    return minimumRollCount;
}

// Checks the rolls present and returns the count.
int getCount(String args) {
    checkLooRoll();
    return looRollCount;
}

// Calibrate the IR sensors.
// 1 = Cal 1 - No rolls.
// 2 = Cal 2 - All rolls populated.
int calibrate(String args) {

    switch (args.toInt()) {
        case 1:
            doRollEmptyCalibration();
            return 1;
        case 2:
            doRollPresentCalibration();
            return 2;
        default:
            return 0;
    }
    
}

// Request to publish calibration details as status post.
// 1: Cal1
// 2: Cal2
// 3: Thresholds.
int getCalibration(String args) {
     switch (args.toInt()) {
        case 1:
            publishStatus("A0:" + String(adcEmpty[0]) + ", A1:" + String(adcEmpty[1]) + ", A2:" + String(adcEmpty[2]) + ", A3:" + String(adcEmpty[3]) + " #Cal1 #RollsAbsent", true);
            return 1;
        case 2:
            publishStatus("A0:" + String(adcFull[0]) + ", A1:" + String(adcFull[1]) + ", A2:" + String(adcFull[2]) + ", A3:" + String(adcFull[3]) + " #Cal2 #RollsPresent", true);
            return 2;
        case 3:
            publishStatus("A0:" + String(adcThresholds[0]) + ", A1:" + String(adcThresholds[1]) + ", A2:" + String(adcThresholds[2]) + ", A3:" + String(adcThresholds[3]) + " #Threshold", true);
            return 3;
        default:
            return 0;
    }
    
}

//////////////////////////////////////////////////////////////////////////////
// Sensor Calibration
//////////////////////////////////////////////////////////////////////////////

// Calibrate the sensors with no rolls on the stand
void doRollEmptyCalibration() {
    
    calibrating = true;
    publishStatus("Performing roll absent calibration.", true);
        
    for (int i=0; i<maxSensors; i++) {
        adcEmpty[i] = (uint16_t)readSensor(i);
    }
    
    publishSenML("{e:[{'n':'A0-Absent','v':'" + String(adcEmpty[0]) + "'},{'n':'A1-Absent','v':'" + String(adcEmpty[1]) + "'},{'n':'A2-Absent','v':'" + String(adcEmpty[2]) + "'},{'n':'A3-Absent','v':'" + String(adcEmpty[3]) + "'},{'n':'Tags','sv':'Cal1,Empty'} ]}");
    
    // Cal 1 performed. Forces cal2 to be redone but assumes values reasobable.
    calibrationState = 1; 
    calibrating = false;
}

// Calibrate the sensors fully fitted with rolls.
// roll present  cal assumes that empty cal has already been performed.
// ADC values for roll present calibration are stored in adcFull at offset 20.
// This assumes cal 1 (empty cal), has been performed.
void doRollPresentCalibration() {
    
    calibrating = true;
    publishStatus("Performing roll present calibration.", true);

    for (int i=0; i<maxSensors; i++) {
        adcFull[i] = (uint16_t)readSensor(i);
    }
    
    publishSenML("{e:[{'n':'A0-Present','v':'" + String(adcFull[0]) + "'},{'n':'A1-Present','v':'" + String(adcFull[1]) + "'},{'n':'A2-Present','v':'" + String(adcFull[2]) + "'},{'n':'A3-Present','v':'" + String(adcFull[3]) + "'},{'n':'Tags','sv':'Cal2,Full'} ]}");

    computeAdcThresholds();
    
    // Cal 2 performed (assumed cal 1 performed)
    calibrationState = 2; 
    writeSettings();
    calibrating = false;
    
}

void computeAdcThresholds() {
    for (int i=0; i<maxSensors; i++) {
        uint16_t empty = adcEmpty[i]; //  higher value (e. 4086)
        uint16_t full = adcFull[i];   // lower value (e.g. 3984)
        
        if (empty > full) {
            
            // e.g. (4086 - 3984)/2 == 51.
            // Compute the midpoint between the full and empty value to determine 
            // the threshold point for the 
            uint16_t halfDifference = (empty - full) / 2;
            
            // take the lower value (full) and add the half difference
            // to give the threshold for detection of the roll.
            // e.g. 3984 + 51 = 4035
            adcThresholds[i] = full + halfDifference;
        } else {
            // Calibration error for this channel
            publishStatus("Calibration error for channel: " + String(i) + " ADC for empty < present.", true);
        }
    }
    
    // Now publish the thresholds (small delay to prevent rate limiting @ particle as a few messages are published during calibration)
    delay(2000);
    publishSenML("{e:[{'n':'A0-Threshold','v':'" + String(adcThresholds[0]) + "'},{'n':'A1-Threshold','v':'" + String(adcThresholds[1]) + "'},{'n':'A2-Threshold','v':'" + String(adcThresholds[2]) + "'},{'n':'A3-Threshold','v':'" + String(adcThresholds[3]) + "'} ]}");
    
    // Publish cal 1 and cal 2 values as well to help debug, with a small delay to prevent rate limiting.
    //delay(1000);
    //Particle.publish("senml", "{e:[{'n':'A0','v':'" + String(adcEmpty[0]) + "'},{'n':'A1','v':'" + String(adcEmpty[1]) + "'},{'n':'A2','v':'" + String(adcEmpty[2]) + "'},{'n':'A3','v':'" + String(adcEmpty[3]) + "'},{'n':'Tags','sv':'Cal1,Empty'} ]}", 60, PRIVATE);
    //delay(1000);
    //Particle.publish("senml", "{e:[{'n':'A0','v':'" + String(adcFull[0]) + "'},{'n':'A1','v':'" + String(adcFull[1]) + "'},{'n':'A2','v':'" + String(adcFull[2]) + "'},{'n':'A3','v':'" + String(adcFull[3]) + "'},{'n':'Tags','sv':'Cal2,Full'} ]}", 60, PRIVATE);
}

//////////////////////////////////////////////////////////////////////////////
// Settings storage
//////////////////////////////////////////////////////////////////////////////
// Memory Map...
// byte    Contenat
// 0       Version
// 1       0: Uncalibdated, 1: Cal1, 2: Cal 2 done.
// 2       Cal 1 valid
// 10      Cal 0 4x 2 array
// 20      Cal 1 4x 2 array.
// 30      ADC threshold values derived from Cal 0 / Cal 1. This determins if a roll is present or not.
// 40      ...
//////////////////////////////////////////////////////////////////////////////

void writeSettings() {
     // Version 1
    EEPROM.write(0, 1);
    // Calibration Stage. 0 = Uncalibrated. 1 = cal1 (empty), 2 = Cal2 (empty), 255 = eeprom default - uncalibrated.
    EEPROM.write(1, calibrationState); 
    EEPROM.write(2, maxSensors); 
    //writeLooRollCount();
    EEPROM.write(4, minimumRollCount);
    EEPROM.put(10, adcEmpty);
    EEPROM.put(20, adcFull);
    EEPROM.put(30, adcThresholds);
}

// This will change frequently so allow it to be 
// set by itself rather than write all the settings 
void writeLooRollCount() {
    //EEPROM.write(3, looRollCount); 
}

void readSettings() {
     
    // read version info.
    uint8_t version = EEPROM.read(0);
    
    if (version == 1) {
        calibrationState = EEPROM.read(1);
        maxSensors = EEPROM.read(2);
       // looRollCount = EEPROM.read(3);
        minimumRollCount = EEPROM.read(4);
        EEPROM.get(10, adcEmpty);
        EEPROM.get(20, adcFull);
        EEPROM.get(30, adcThresholds);
    } else {
        publishStatus("Using default values. Calibration required", true);
    }
}
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

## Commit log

2016-04-18 Top and middle boards as sent to DirtyPcbs
    [LooRollSensorMiddleBoard.brd, LooRollSensorMiddleBoard.sch, LooRollSensorTop.brd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]
2016-04-18 Work in progress water detect bottom board
    [WaterDetector.brd, WaterDetector.sch]
2016-04-18 Water detect board V1.00 as sent to DirtyPCBs
    [WaterDetector.brd, WaterDetector.sch]
2016-08-23 Moved PCB files to a dedicated folder.
    [LooRollSensorMiddleBoard.brd, LooRollSensorMiddleBoard.sch, LooRollSensorTop.brd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]
2016-08-23 Added 3D printer files to make the base and the top.
    [Base-2.stl, Base-AAA.stl, Base.scad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]
2016-08-23 Work in progress firmware. Basics in, calibration working. Water sense not.
2016-08-23 Added work in progress BOM and the .gitignore file.
    [BOM.xlsx]
2016-08-23 Fixed water sense as it's active low. Added publishing on water sense cleared.
    Set Photon LED to be red if low roll count or water sensed.
    Decreased time before debug mode is existed to 60 seconds, although this might be a bit short.
    Modified debug sleep to monitor water sense rather than a solid 10s sleep.
    [LooRollMonitor.ino]
2016-08-24 Changed field name for WaterSensed as it's not an ADC value.
    Implemented send state (roll count etc) measurements on every wake loop.
2016-08-27 Update to ensure calibration does not happen at the same time as other checking functions.
    Increased initial debug timeout before power saving kicks in.
    Added sensor ADC values to status publishing to help watch for anomolies.
    Modified reasSensor to remove background IR and to have longer delays for reading and between reading IR reflectance levels.
2016-08-27 Added missing junctions
    [LooRollSensorMiddleBoard.sch]
2016-08-28 Removed VBattAdcThreshold in favour of a direct voltage threshold which is easier to understand.
    Added iSCritical to publishStatus so that a delay can be added to the publishing to ensure the message has gone (pending Photon firmware update that includes confirmation).
    Added flag to publishStatus to indicate if a published message may be waiting to allow the deep sleep to be delayed so the messages can be published by the photon.
    Stopped roll monitoring and publishing when the battery level is low to slow down draining the batteries which can be bad for them.
2016-08-30 Added bodge resistor required to pull LED drive low to prevent LEDs switching on when Photon is in power save mode.
    "Printed" eagle files as pdfs.
    [LooRollSensorTop.brd, LooRollSensorTop.sch, WaterDetector.sch]
2016-08-30 Added use of retained variables to keep values in memory when in deep power mode.
    Adde monitoring of time to connect to the cloud and time from wake to sleep.
    Added ability to pusblish calibration values on demand.

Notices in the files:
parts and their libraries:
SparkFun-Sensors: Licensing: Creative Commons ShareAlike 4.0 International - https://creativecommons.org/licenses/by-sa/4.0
